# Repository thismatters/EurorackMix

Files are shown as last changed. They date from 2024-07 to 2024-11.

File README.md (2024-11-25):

# Mix

Audio signal mixing. Basic module with simple OP Amp design.

The KiCAD project here uses the library/footprints [found in my companion repo](https://github.com/thismatters/EurorackKiCAD).

## Size

30hp on a 1u rack.

## Inputs

4x patch inputs and 4x potentiometers for adjusting the apparent effect of a patch input

## Outputs

Single 1/4" phone jack output.
4 LED array indicating output level.

## Notes

LED array takes some cues from the [MFOS Multifunction Module](https://musicfromouterspace.com/analogsynth_new/MULTIFUNCTIONMODULE/pdf/mfm_schempg1_schem.pdf)

## Vendors

There are part numbers in the [BOM](mix.csv) for many of the parts (not for basic passives though) at the following vendors:

* [Mouser](https://www.mouser.com): Needs no introduction. Get your ICs from here (or [digikey](https://www.digikey.com)).
* [Tayda Electronics](https://www.taydaelectronics.com/): Good supplier for passive components; audio jacks, and potentiometers. Their audio jacks are slightly smaller than the thonkiconn from thonk.
* [Love My Switches](https://lovemyswitches.com/): Has [really good knobs](https://lovemyswitches.com/anodized-aluminum-knob-the-lo-fi-1-4-smooth-shaft-12-5mm-od/) to go on those potentiometers!
* [OSHPark](https://oshpark.com/): Fast and (relatively) cheap PCB manufacturer. The [V0 circuit](https://oshpark.com/shared_projects/xlEAsl8K) works pretty well as a mix, but the output level indicator doesn't quite work right, there will be another version.

## Changelog

### V1
- [x] Adds full bridge rectifier to output level indicator
- [x] Adds capacitor and resistor to output level indicator
- [x] Removes capacitor from output op amp
- [x] Updates design langage

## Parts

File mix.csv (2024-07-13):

# | Reference | Qty | Value | Footprint | DNP | Vendor | PartNum
1 | C1, C2 | 2 | 22u 50V | Capacitor_THT:CP_Radial_D5.0mm_P2.50mm
2 | C3, C4 | 2 | 100n | Capacitor_SMD:C_0805_2012Metric
3 | C5 | 1 | 15p | Capacitor_SMD:C_0805_2012Metric
4 | D1, D2 | 2 | BAT54S | Package_TO_SOT_SMD:SOT-23 |  | Mouser | 863-BAT54SLT1G
5 | D3 | 1 | LED_ORANGE | LED_THT:LED_D3.0mm
6 | D4, D5, D6 | 3 | LED_GREEN | LED_THT:LED_D3.0mm
7 | J1 | 1 | Conn_02x05_Odd_Even | Eurorack:PinHeader_2x05_P2.54mm_Vertical |  | Tayda | A-2939
8 | J2, J3, J4, J5 | 4 | AudioJack2_SwitchT | Eurorack:AudioJack2_Tayda_A-2566 |  | Tayda | A-2566
9 | J6 | 1 | AudioJack2 | Eurorack:AudioJack2_Tayda_A-1009 |  | Tayda | A-1009
10 | Q1, Q2 | 2 | BCM847 | Package_SO:TSOP-6_1.65x3.05mm_P0.95mm |  | Mouser | 771-BCM847DS135
11 | R1, R2 | 2 | 10 | Resistor_SMD:R_0805_2012Metric
12 | R3, R4, R5, R6, R7, R8, R9, R15, R16, R17, R18, R19 | 12 | 100K | Resistor_SMD:R_0805_2012Metric
13 | R10 | 1 | 1K | Resistor_SMD:R_0805_2012Metric
14 | R11 | 1 | 300K | Resistor_SMD:R_0805_2012Metric
15 | R12, R13, R14 | 3 | 270K | Resistor_SMD:R_0805_2012Metric
16 | R20, R21, R22, R23 | 4 | 470 | Resistor_SMD:R_0805_2012Metric
17 | RV1, RV2, RV3, RV4 | 4 | A250K | Eurorack:Potentiometer_RV16AF-41-15R1
18 | U1 | 1 | TL074 | Package_SO:SOIC-14_3.9x8.7mm_P1.27mm |  | Mouser | 595-TL074CDR
19 | U2 | 1 | TL072 | Package_SO:SOIC-8_3.9x4.9mm_P1.27mm |  | Mouser | 595-TL072CDR

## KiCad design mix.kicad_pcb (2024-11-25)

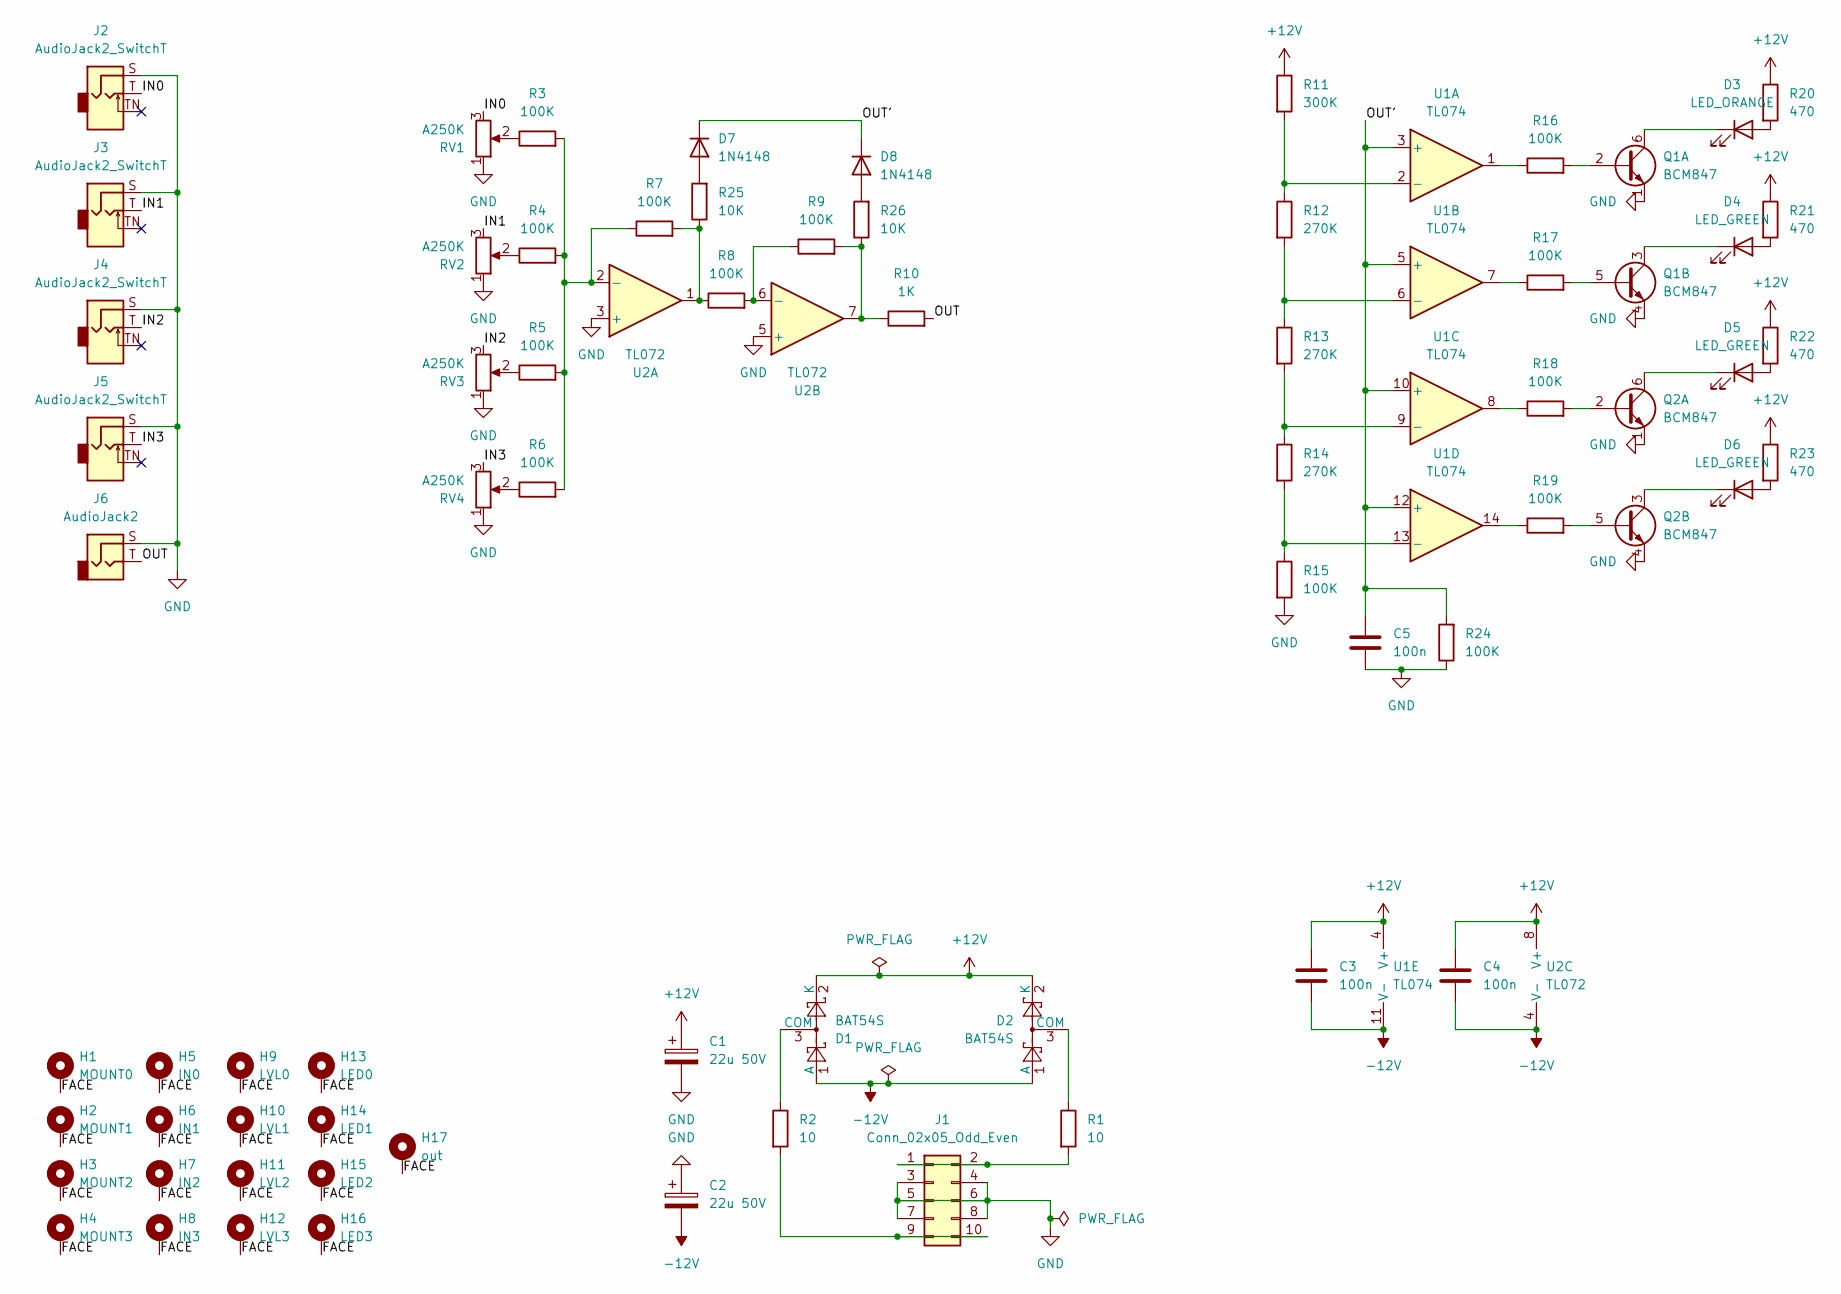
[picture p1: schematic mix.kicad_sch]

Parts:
C1, C2: 22u 50V; CP_Radial_D5.0mm_P2.50mm
C3, C4, C5: 100n; C_0805_2012Metric
D1, D2: BAT54S; SOT-23; PartNum 863-BAT54SLT1G
D3: LED_ORANGE; LED_D3.0mm
D4, D5, D6: LED_GREEN; LED_D3.0mm
D7, D8: 1N4148; D_SOD-323_HandSoldering
H1: MOUNT0; Mech-MountingHole
H2: MOUNT1; Mech-MountingHole
H3: MOUNT2; Mech-MountingHole
H4: MOUNT3; Mech-MountingHole
H5: IN0; Mech-AudioJack-Hole-Input
H6: IN1; Mech-AudioJack-Hole-Input
H7: IN2; Mech-AudioJack-Hole-Input
H8: IN3; Mech-AudioJack-Hole-Input
H9: LVL0; Mech-Potentiometer-Hole_level_90deg
H10: LVL1; Mech-Potentiometer-Hole_level_90deg
H11: LVL2; Mech-Potentiometer-Hole_level_90deg
H12: LVL3; Mech-Potentiometer-Hole_level_90deg
H13: LED0; Mech-LED-Hole-3mm-Bezel
H14: LED1; Mech-LED-Hole-3mm-Bezel
H15: LED2; Mech-LED-Hole-3mm-Bezel
H16: LED3; Mech-LED-Hole-3mm-Bezel
H17: out; Mech-Hole-10mm; PartNum 595-TL072CDR
J1: Conn_02x05_Odd_Even; PinHeader_2x05_P2.54mm_Vertical; PartNum A-2939
J2, J3, J4, J5: AudioJack2_SwitchT; AudioJack2_Tayda_A-2566; PartNum A-2566
J6: AudioJack2; AudioJack2_Tayda_A-1009; PartNum A-1009
Q1, Q2: BCM847; TSOP-6_1.65x3.05mm_P0.95mm; PartNum 771-BCM847DS135
R1, R2: 10; R_0805_2012Metric
R3, R4, R5, R6, R7, R8, R9, R15, R16, R17, R18, R19, R24: 100K; R_0805_2012Metric
R10: 1K; R_0805_2012Metric
R11: 300K; R_0805_2012Metric
R12, R13, R14: 270K; R_0805_2012Metric
R20, R21, R22, R23: 470; R_0805_2012Metric
R25, R26: 10K; R_0805_2012Metric
RV1, RV2, RV3, RV4: A250K; Potentiometer_RV16AF-41-15R1
U1: TL074; SOIC-14_3.9x8.7mm_P1.27mm; PartNum 595-TL074CDR
U2: TL072; SOIC-8_3.9x4.9mm_P1.27mm; PartNum 595-TL072CDR

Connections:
+12V: C1.1, C3.1, C4.1, D1.2 (K), D2.2 (K), R11.1, R20.1, R21.1, R22.1, R23.1, U1.4 (V+), U2.8 (V+)
-12V: C2.2, C3.2, C4.2, D1.1 (A), D2.1 (A), U1.11 (V-), U2.4 (V-)
/FACE: H1.1, H2.1, H3.1, H4.1, H5.1, H6.1, H7.1, H8.1, H9.1, H10.1, H11.1, H12.1, H13.1, H14.1, H15.1, H16.1, H17.1
/IN0: J2.T, RV1.3
/IN1: J3.T, RV2.3
/IN2: J4.T, RV3.3
/IN3: J5.T, RV4.3
/OUT: J6.T, R10.2
/OUT': C5.1, D7.1 (K), D8.1 (K), R24.2, U1.3 (+), U1.5 (+), U1.10 (+), U1.12 (+)
GND: C1.2, C2.1, C5.2, J1.3, J1.4, J1.5, J1.6, J1.7, J1.8, J2.S, J3.S, J4.S, J5.S, J6.S, Q1.1 (E1), Q1.4 (E2), Q2.1 (E1), Q2.4 (E2), R15.2, R24.1, RV1.1, RV2.1, RV3.1, RV4.1, U2.3 (+), U2.5 (+)
unnamed: D1.3 (COM), R2.1
unnamed: D2.3 (COM), R1.1
unnamed: D3.2 (A), R20.2
unnamed: D3.1 (K), Q1.6 (C1)
unnamed: D4.2 (A), R21.2
unnamed: D4.1 (K), Q1.3 (C2)
unnamed: D5.2 (A), R22.2
unnamed: D5.1 (K), Q2.6 (C1)
unnamed: D6.2 (A), R23.2
unnamed: D6.1 (K), Q2.3 (C2)
unnamed: D7.2 (A), R25.2
unnamed: D8.2 (A), R26.2
unnamed: J1.1, J1.2, R1.2
unnamed: J1.9, J1.10, R2.2
unnamed: Q1.2 (B1), R16.2
unnamed: Q1.5 (B2), R17.2
unnamed: Q2.2 (B1), R18.2
unnamed: Q2.5 (B2), R19.2
unnamed: R3.1, RV1.2
unnamed: R4.1, RV2.2
unnamed: R5.1, RV3.2
unnamed: R6.1, RV4.2
unnamed: R9.2, R10.1, R26.1, U2.7
unnamed: R16.1, U1.1
unnamed: R17.1, U1.7
unnamed: R18.1, U1.8
unnamed: R19.1, U1.14
unnamed: R7.2, R8.1, R25.1, U2.1
unnamed: R11.2, R12.1, U1.2 (-)
unnamed: R12.2, R13.1, U1.6 (-)
unnamed: R13.2, R14.1, U1.9 (-)
unnamed: R14.2, R15.1, U1.13 (-)
unnamed: R3.2, R4.2, R5.2, R6.2, R7.1, U2.2 (-)
unnamed: R8.2, R9.1, U2.6 (-)

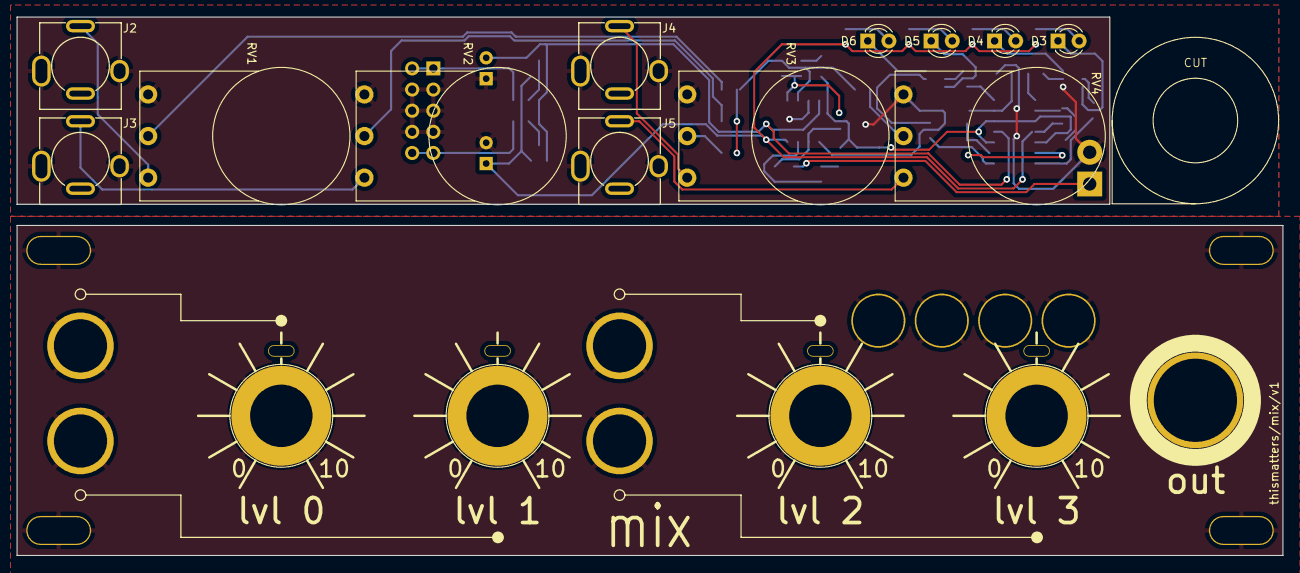
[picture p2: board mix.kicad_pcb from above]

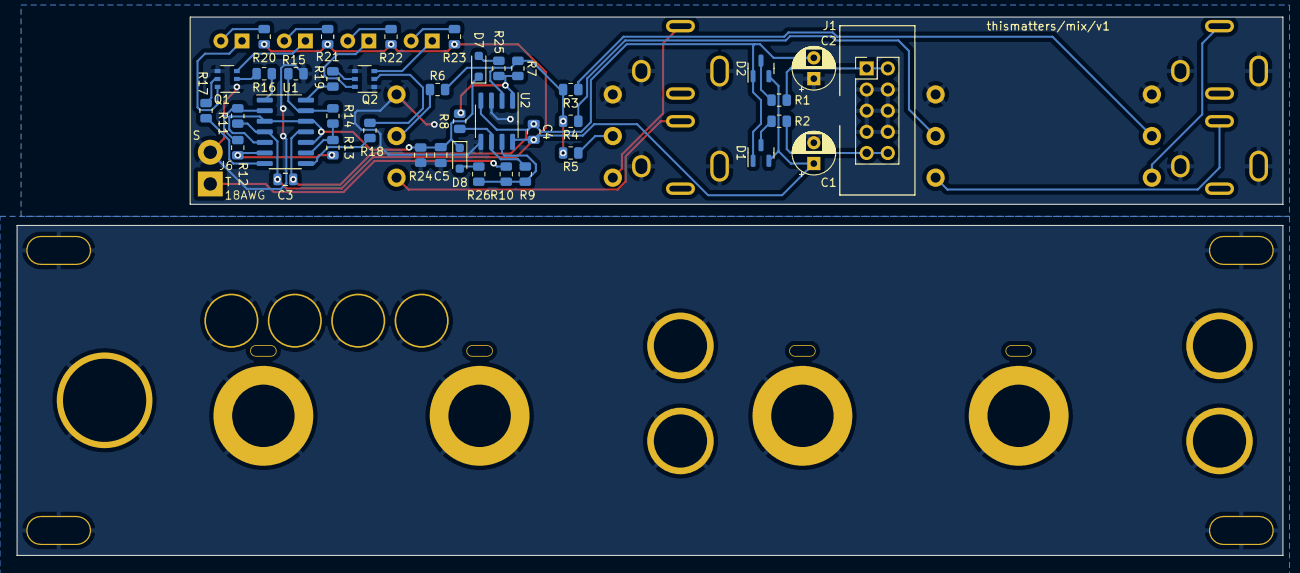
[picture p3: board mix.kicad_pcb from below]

Board: 2 copper layers, 152.1 x 64.7 mm, 70 parts (40 on the bottom side), 44 nets.

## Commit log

2024-07-13 pcb layed out
    [mixout.kicad_pcb, mixout.kicad_sch]
2024-07-13 Fixing BOM
    [mixout.csv]
2024-07-13 renaming project
    [mix.csv, mix.kicad_pcb, mix.kicad_sch]
2024-11-25 adding pcb to readme
    [mix.kicad_pcb, mix.kicad_sch]
